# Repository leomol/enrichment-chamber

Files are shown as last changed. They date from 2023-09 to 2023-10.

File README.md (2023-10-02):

# Enrichment chamber
CAD files and assembly instructions for an enrichment chamber with optional RFID sensors.<br>
All the floors, the ladders, and the mazes are removable.<br>
Required CAD files for laser cutting are provided.<br>
Optional code to create the CAD files programmatically (including option to adjust the kerf) is provided in `main.m`.<br>
Mazes can be designed with simple text instructions (see 6 examples at the end of `main.m`).<br>

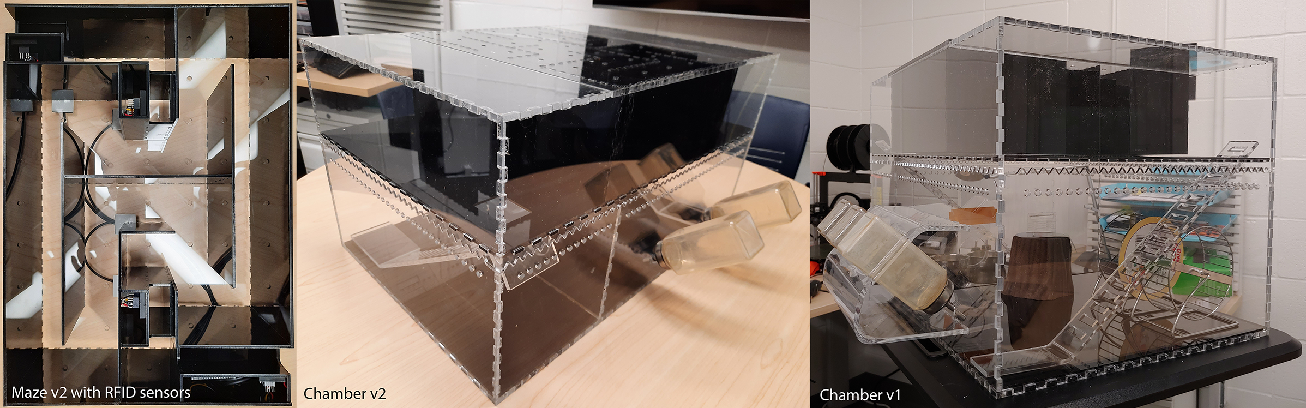
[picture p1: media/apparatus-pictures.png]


See related resources:
- [CAD library][cad-library]

## Components
- [6mm clear acrylic sheets](https://www.polymershapes.com/product/acrylic/)
- [3mm black acrylic sheets](https://www.polymershapes.com/product/acrylic/)

## Assembly instructions
- Laser cut the acrylic sheets using the [provided CAD drawings](CAD). Remove protective film.
- Assemble all acrylic parts (except removable parts) using painter's tape and apply acrylic cement or 2-part epoxy.
- Remove painter's tape after drying.
- Heat the ladders at the folding lines of the drawing using a heat gun and bend to accomplish the shape shown in the pictures.

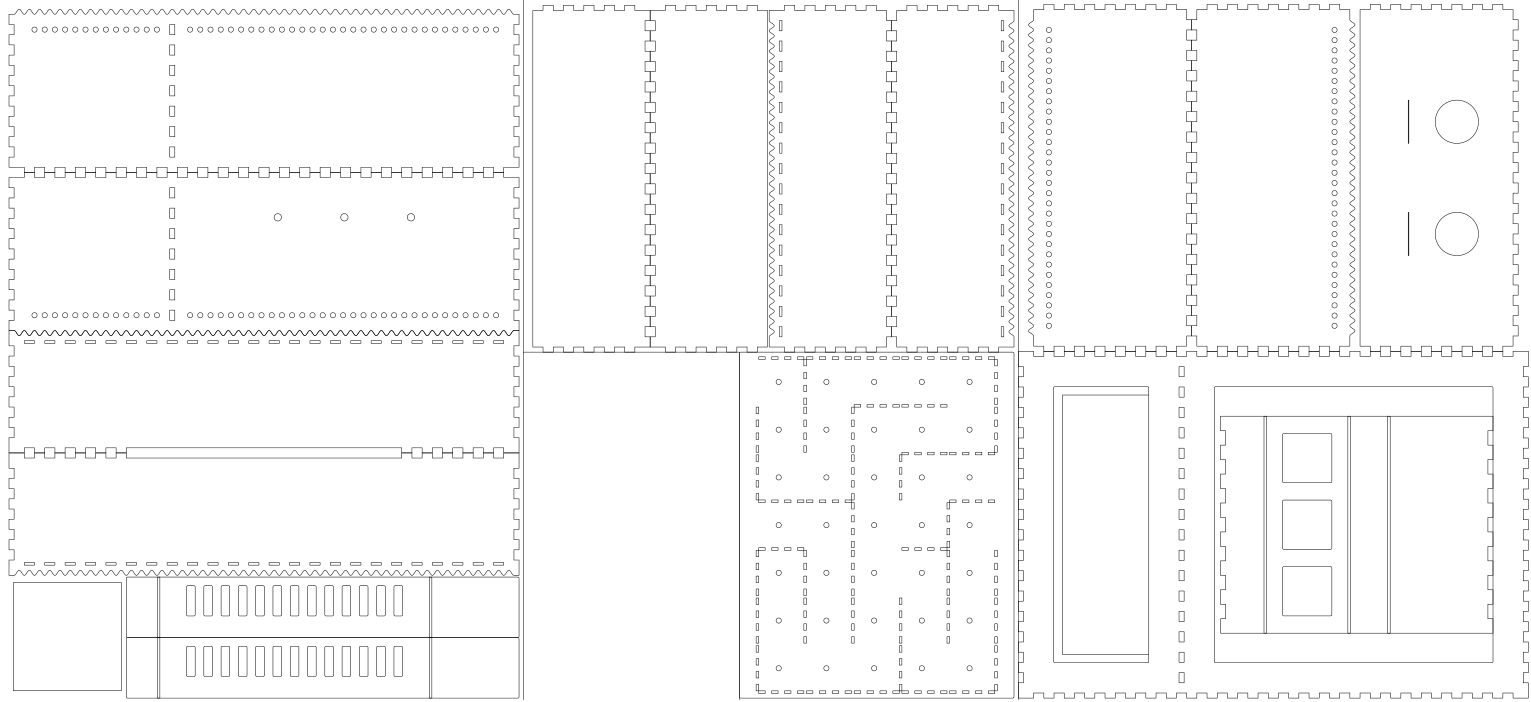
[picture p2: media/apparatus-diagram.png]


## Recreating CAD files programmatically
### Prerequisites
- [MATLAB][MATLAB] (last tested with R2023a)

### Installation
- Install [MATLAB][MATLAB]
- Download and extract the [CAD library][cad-library] to the `Documents/MATLAB` folder (see [the library's installation instructions][cad-library]).
- Download and extract the [project scripts][cad-scripts] to `Documents/MATLAB` folder.
- Edit sizes and maze designs and run `main.m`.

## RFID add-on
Optional RFID sensors can be used to track a subject navigating throught the maze.

### Components
- 1 x [Arduino Mega 2560 Rev 3](https://store.arduino.cc/products/arduino-mega-2560-rev3)
- 4 x [ID-12LA RFID sensors](https://www.mouser.ca/ProductDetail/SparkFun/SEN-11827?qs=WyAARYrbSnbkXY1Fl9rz%2Fw%3D%3D)
- 2 x [220uF electrolylic capacitors](https://www.mouser.ca/ProductDetail/KEMET/ESK227M016AE3EA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)
- [125Khz RFID tags](https://www.mouser.ca/ProductDetail/SparkFun/SEN-09416?qs=WyAARYrbSnYupkaxZp2N0w%3D%3D)
- [Shielded cable with 3 conductors](https://www.digikey.ca/en/products/detail/tensility-international-corp/30-00377/5270246)
- [Fuse Tape](https://www.amazon.ca/gp/product/B0018BVNIS)

### Software prerequisites
- [Python][Python] (last tested with Python 3.9)
- [PySerial](https://pyserial.readthedocs.io/en/latest/pyserial.html)

### Instructions
- Repeat assembly instructions above for the microcontroller and RFID sensor enclosures.
- Wire each RFID sensor according to the manufacturer [instructions](https://www.mouser.ca/datasheet/2/813/ID_2LA_2c_ID_12LA_2c_ID_20LA2013_4_10-2489776.pdf) for ASCII output (`Pin 2` to `VDC` and `Pin 7` to `GND`) and connect the data pin `D0` from each sensor to `RX1`, `RX2`, `RX3` and `A8` pins of the Arduino Mega. Insert RFID enclosures, the microcontroller and wired sensors through the holes of maze `z1`.
- Using fuse tape, attach the sensors to the bottom of each casing, facing the maze path, making sure they all face the same side. 
- Upload the [Arduino code][rfid-scripts] to the microcontroller using [Arduino IDE](https://www.arduino.cc/en/software)
- Connect the usb cable to the computer and monitor the outputs using a [serial monitor program](src/rfid/SerialCapture.py).

## Using Serial Capture
- Using python start the acquisition program with `python SerialCapture.py`
- Stop capturing by pressing `ctrl+c`
- Data is saved to the `Documents` folder as a `csv` file with the data and time encoded in the filename.

## Changelog
See [Changelog](CHANGELOG.md)

## License
© 2021 [Leonardo Molina][Leonardo Molina]

### License for the aparatus and CAD files
[Creative Commons BY-NC-SA 4.0 License][cad-license]

### License for the source code
[GNU GPLv3 License][code-license]

[cad-library]: https://github.com/leomol/cad
[cad-scripts]: src/CAD/
[rfid-scripts]: src/RFID/
[Leonardo Molina]: https://github.com/leomol
[MATLAB]: https://www.mathworks.com/downloads/
[Python]: https://www.python.org/downloads/
[code-license]: src/LICENSE.md
[cad-license]: CAD/LICENSE.md

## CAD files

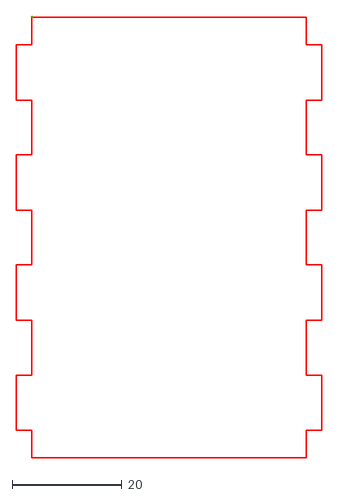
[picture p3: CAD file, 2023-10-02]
CAD/RFID/ShortFrontWall.dxf
55.9 x 80.7

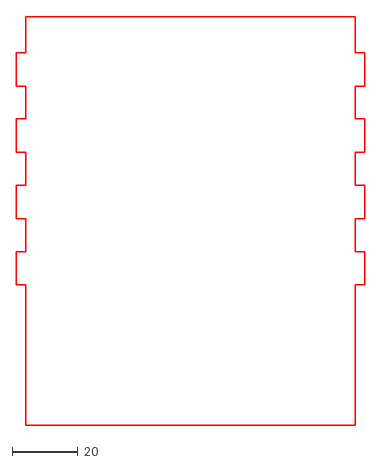
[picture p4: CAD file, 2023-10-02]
CAD/RFID/WideBackWall.dxf
105.8 x 124.1

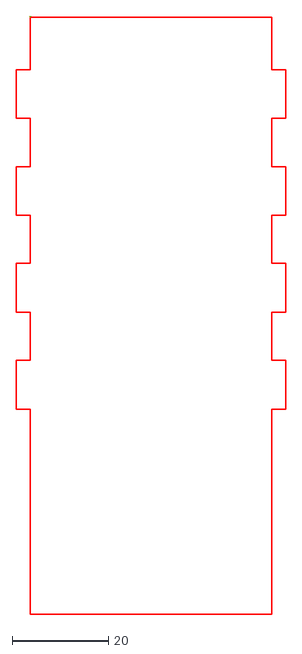
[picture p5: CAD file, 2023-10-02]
CAD/RFID/ShortBackWall.dxf
55.9 x 124.1

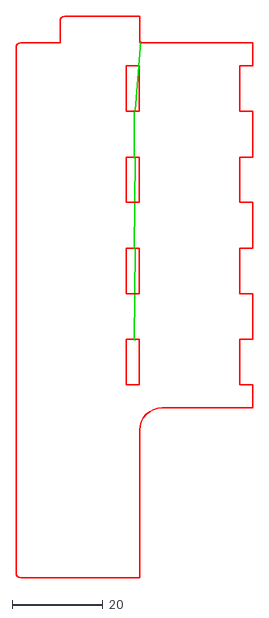
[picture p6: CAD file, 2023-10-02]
CAD/RFID/SideWalls.dxf
52.2 x 123.8

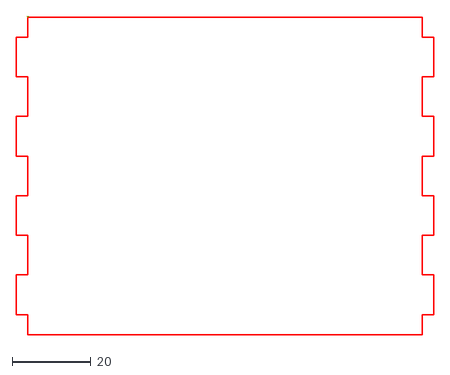
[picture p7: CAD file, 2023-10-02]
CAD/RFID/WideFrontWall.dxf
105.8 x 80.7

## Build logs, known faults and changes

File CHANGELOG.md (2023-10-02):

## CAD files changelog
* 2023-09-22 (v0.1.2)
	- Added maze `z1`.
	- Removed `bottleHolder` (use alternative listed in 2023-09-12).
	- Added RFID enclosures for maze `z1`.
	- Added RFID sensors, Arduino microcontroller and control code.
	- Added `SerialCapture.py` to log data.
	- Changed `mazeWallThickness` from 3.00mm to 2.90mm (parts regenerated; layouts not updated except for `RFID maze z1.svg`).
	- Increased length of maze guide to provide a lip to facilitate removal.
	- Edited apparatus picture to reflect both old and new versions.
* 2023-09-12 (v0.1.1)
	- Updated size to save material in sheets measuring 32x49"
	- Provided alternative bottle holder using nuts (drawn by hand).
	- Changed design of ladder (requires heat gun to bend to desired shape).
* 2020-08-24 (v0.1.0)
	- Initial design as in the picture.

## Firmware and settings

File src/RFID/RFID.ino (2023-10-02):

/**
 * @brief Arduino control program to report RFID tag detection from 4 RFID sensors in the Enrichment Chamber.
 * @author Leonardo Molina (leonardomt@gmail.com).
 * @file RFID.ino
 * @date 2023-10-03
 * @version: 0.1.0
*/

#include <SoftwareSerial.h>
#define PC Serial
#define S1 Serial1
#define S2 Serial2
#define S3 Serial3

SoftwareSerial S4(A8, A8);

const uint8_t nRF = 4;
Stream* RF[nRF];

// Baudrate of serial communication with the PC.
const uint32_t baudrate = 115200;
uint8_t tag[20] = {0};
uint8_t tagSize = 0;

void setup() {
	// Start both hardware and software serial streams.
	S1.begin(9600);
	S2.begin(9600);
	S3.begin(9600);
	S4.begin(9600);
	
	RF[0] = &S1;
	RF[1] = &S2;
	RF[2] = &S3;
	RF[3] = &S4;
	
	// Wait for connection from PC.
	PC.begin(baudrate);
	while (!PC)
		delay(10);
	
	// Report start with expected format.
	PC.println("0,0,0");
}

/** 
 * Check for incoming messages from any of the RFID sensors.
 */
void loop() {
	int8_t i = 0;
	for (int8_t i = 0; i < nRF; i++) {
		// Parse data from RFID reader.
		while (RF[i]->available() > 0) {
			// Data format: 2, a, b, ..., 10, 13, 3
			char input = RF[i]->peek();
			if (input == 2) { // STX.
				RF[i]->read();
				tagSize = 0;
			} else if (input == 3) { // ETX.
				tagSize -= 2; // Do not include 10 and 13
				RF[i]->read();
				reportTag(i);
			} else {
				tag[tagSize++] = RF[i]->read();
			}
		}
	}
}

/** 
 * Report timestamp, sensor id, and tag detected.
 *
 * # @param sensorId Id of RFID sensor.
*/
void reportTag(uint8_t sensorId) {
	char const hex[16] = {'0', '1', '2', '3', '4', '5', '6', '7', '8', '9', 'A', 'B', 'C', 'D', 'E', 'F'};
	PC.print(String() + millis() + "," + sensorId + ",");
	for (int i = 0; i < tagSize; i++) {
		PC.print(hex[(tag[i] & 0xF0) >> 4]);
		PC.print(hex[(tag[i] & 0x0F) >> 0]);
	}
	PC.println();
}

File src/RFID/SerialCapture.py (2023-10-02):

# 2023-03-17. Leonardo Molina.
# 2023-03-17. Last modified.

# Save to disk any data captured from the first serial port that sends data within 1 second.
# Data is expected to be separated by new lines.

import serial
import serial.tools.list_ports
import signal
import sys
import threading
import time

from pathlib import Path
from datetime import datetime

class Capture(object):
    def __init__(self, output, baudrate=115200):
        self.event = threading.Event()
        self.lock = threading.Lock()
        self.lines = []
        self.baudrate = baudrate
        self.output = output
        self.serial = self.__connect()
        self.savingThread = threading.Thread(target=self.__savingThread)
        self.readingThread = threading.Thread(target=self.__readingThread)
        
        self.savingThread.start()
        self.readingThread.start()
    
    def dispose(self):
        self.event.set()
        self.join()
        self.serial.close()
        
    def join(self):
        self.savingThread.join()
        self.readingThread.join()
        
    @property
    def running(self):
        return not self.event.is_set()
    
    def __readingThread(self):
        while self.running:
            if self.serial.in_waiting:
                line = self.serial.readline().decode().strip()
                with self.lock:
                    self.lines.append(line)
            else:
                time.sleep(1e-3)
    
    def __savingThread(self):
        while self.running:
            self.__dump()
            time.sleep(0.1)
        self.__dump()
            
    def __dump(self):
        with self.lock:
            lines, self.lines = self.lines, []
        with open(self.output, 'a') as file:
            for line in lines:
                print('  %s' % line)
                file.write(line + '\n')
    
    def __connect(self):
        ports = list(serial.tools.list_ports.comports())
        for port in ports:
            try:
                s = serial.Serial(port.device, self.baudrate, timeout=1.0)
                line = s.readline().decode().strip()
                if line:
                    self.lines.append(line)
                    print('Connected to "%s"' % port.device)
                    return s
            except serial.SerialException:
                pass
        raise Exception('No device found')

def dispose(capture):
    print('Closing')
    capture.dispose()
    print('Finished')

if __name__ == '__main__':
    print('Started.')
    dateString = datetime.now().strftime('%Y%m%d-%H%M%S')
    output = Path.home() / 'Documents' / dateString
    output = str(output) + '.csv'
    print('Output file: "%s"' % output)
    
    # Run until interrupted with ctrl+c.
    capture = Capture(output=output)
    signal.signal(signal.SIGINT, lambda sig, frame: dispose(capture))
    signal.signal(signal.SIGTERM, lambda sig, frame: dispose(capture))
    while capture.running:
        time.sleep(0.1)
